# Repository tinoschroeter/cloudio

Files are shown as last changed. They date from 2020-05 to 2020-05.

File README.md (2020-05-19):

## Cloudio dein IoT Office buddy





Cloudio ueberwacht die Temperatur und Luftqualitaet. 
laesst sich mit Prometheus ansprechen um Grafana Metriken zu bekommen.

Und wenn es ganz schlimm wird, geht eine Slack Benachrichtigung raus.

[work in progress]

https://github.com/ozhantr/DigitLedDisplay

* Firebase 
  * Functions
  * Realtime Database 
  * Hosting
  * Authentication
* Prometheus
* Grafana
* Arduino
* ESP8266
* NodeJs
* JavaScript
* p5.js

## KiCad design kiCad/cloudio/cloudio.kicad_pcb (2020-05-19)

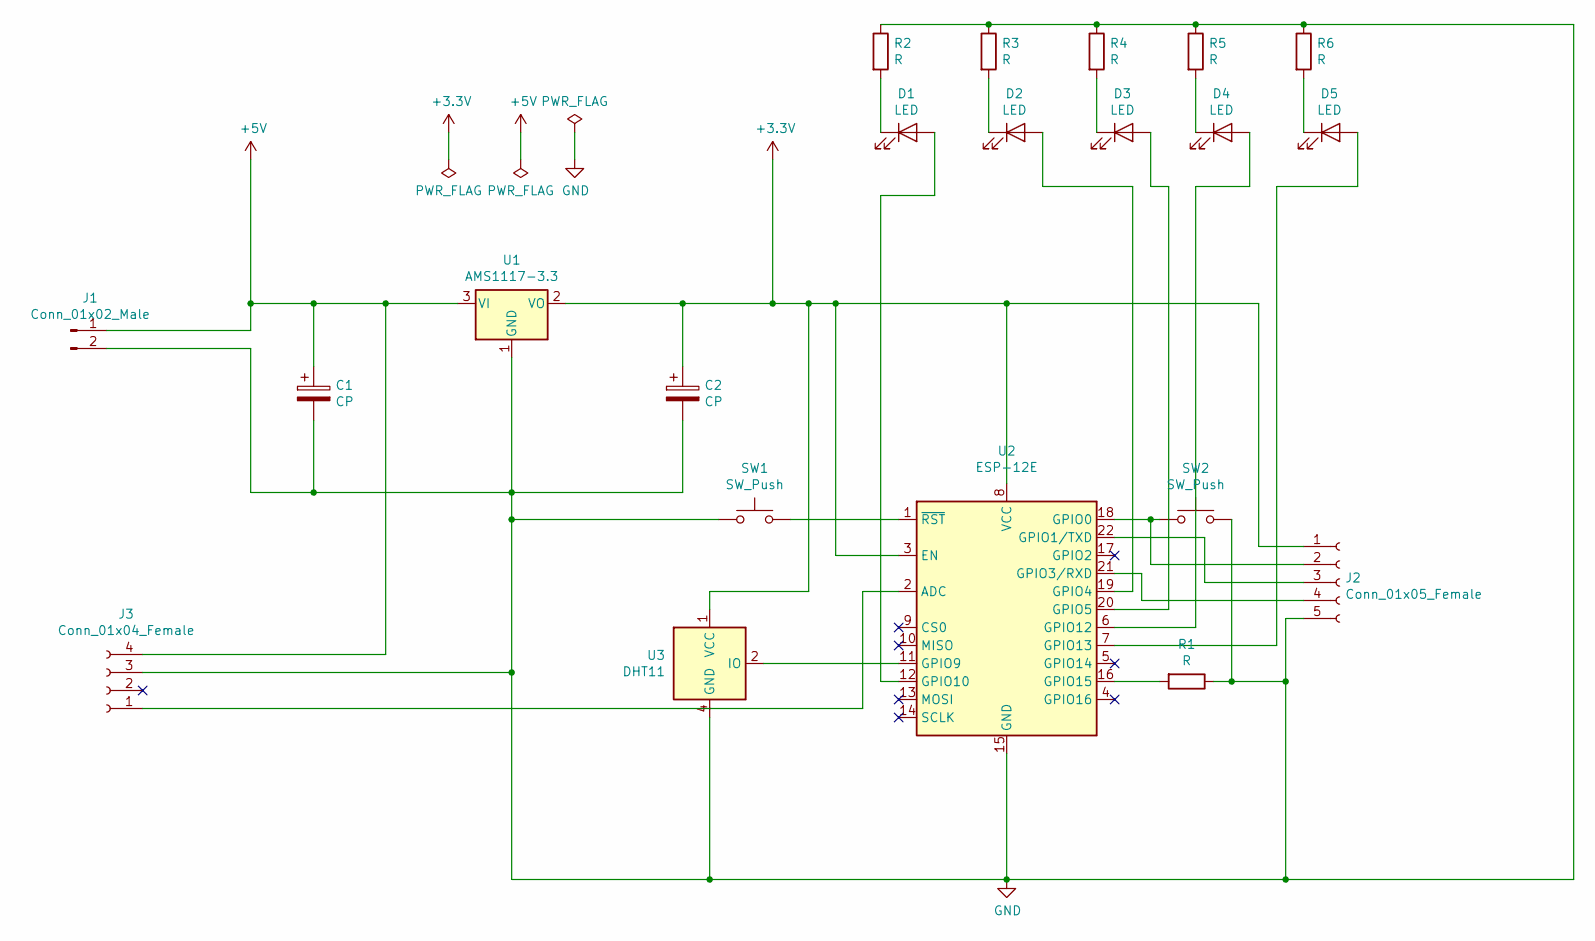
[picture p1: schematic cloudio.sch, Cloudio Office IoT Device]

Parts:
C1, C2: CP; CP_Radial_D4.0mm_P2.00mm
D1, D2, D3, D4, D5: LED; LED_Rectangular_W5.0mm_H2.0mm
J1: Conn_01x02_Male; PinHeader_1x02_P1.27mm_Vertical
J2: Conn_01x05_Female; PinHeader_1x05_P1.27mm_Vertical
J3: Conn_01x04_Female; PinHeader_1x04_P1.27mm_Vertical
R1, R2, R3, R4, R5, R6: R; R_0805_2012Metric_Pad1.15x1.40mm_HandSolder
SW1, SW2: SW_Push; SW_Push_1P1T_NO_CK_KSC7xxJ
U1: AMS1117-3.3; SOT-223-3_TabPin2
U2: ESP-12E
U3: DHT11; Aosong_DHT11_5.5x12.0_P2.54mm

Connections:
+3V3: C2.1, J2.1, U1.2 (VO), U2.3 (EN), U2.8 (VCC), U3.1 (VCC)
+5V: C1.1, J1.1, J3.4, U1.3 (VI)
GND: C1.2, C2.2, J1.2, J2.5, J3.3, R1.1, R2.1, R3.1, R4.1, R5.1, R6.1, SW1.1, SW2.2, U1.1 (GND), U2.15 (GND), U3.4 (GND)
unnamed: D1.1 (K), R2.2
unnamed: D1.2 (A), U2.12 (GPIO10)
unnamed: D2.1 (K), R3.2
unnamed: D2.2 (A), U2.19 (GPIO4)
unnamed: D3.1 (K), R4.2
unnamed: D3.2 (A), U2.20 (GPIO5)
unnamed: D4.1 (K), R5.2
unnamed: D4.2 (A), U2.6 (GPIO12)
unnamed: D5.1 (K), R6.2
unnamed: D5.2 (A), U2.7 (GPIO13)
unnamed: J2.2, SW2.1, U2.18 (GPIO0)
unnamed: J2.3, U2.22 (GPIO1/TXD)
unnamed: J2.4, U2.21 (GPIO3/RXD)
unnamed: J3.1, U2.2 (ADC)
unnamed: R1.2, U2.16 (GPIO15)
unnamed: SW1.2, U2.1 (~RST)
unnamed: U2.11 (GPIO9), U3.2 (IO)

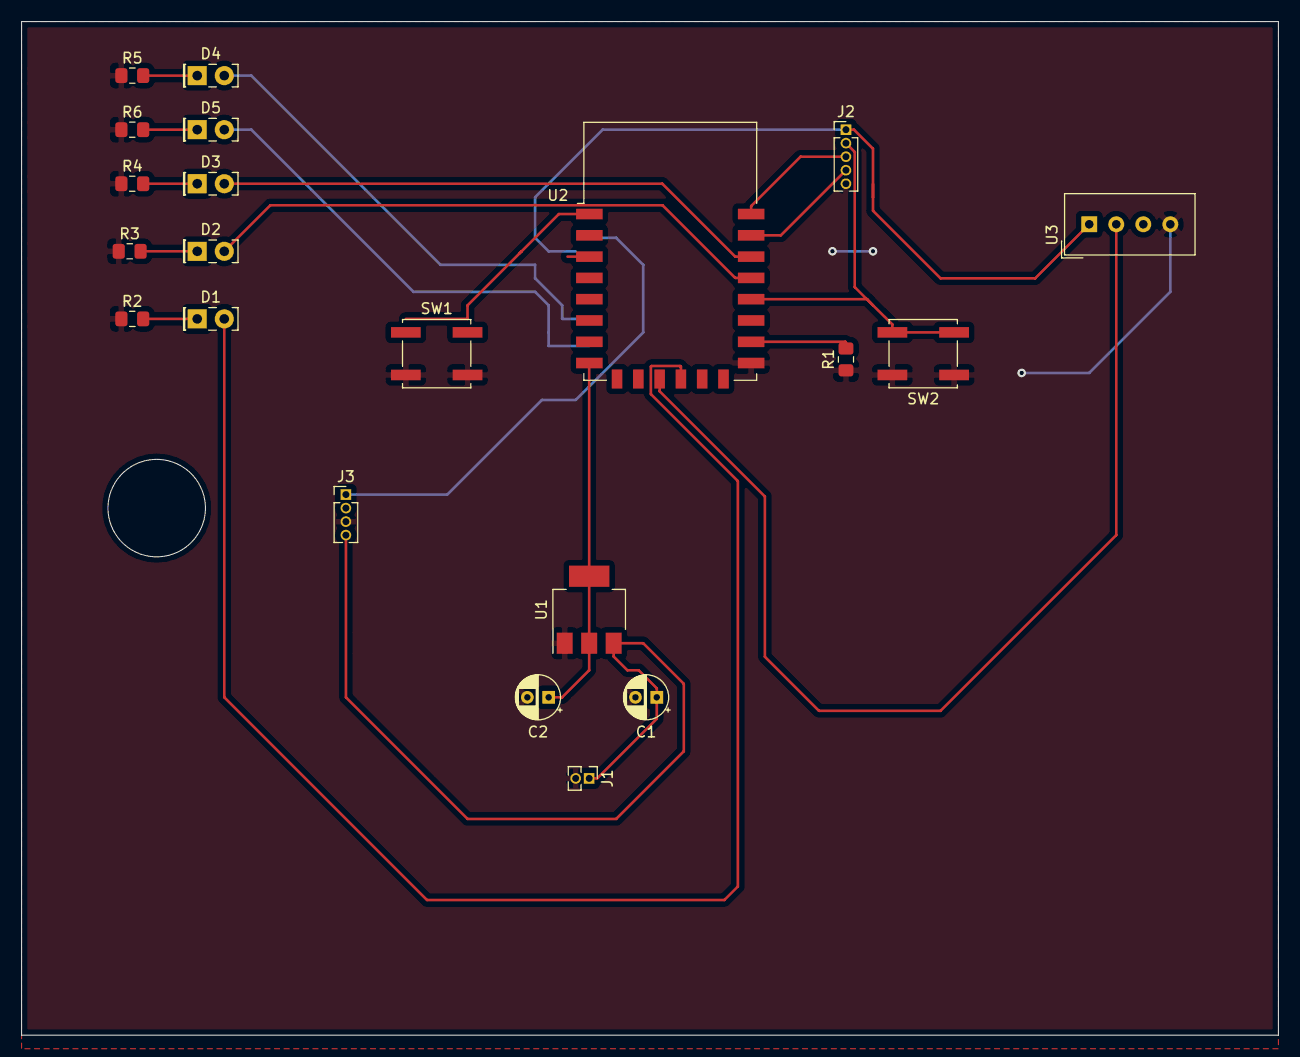
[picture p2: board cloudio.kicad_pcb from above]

Board: 2 copper layers, 118.1 x 95.2 mm, 21 parts (0 on the bottom side), 20 nets.

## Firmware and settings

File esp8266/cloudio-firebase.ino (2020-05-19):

// esp8266 community version: 2.5.2
#include <ESP8266WiFi.h>
#include <SoftwareSerial.h>
#include <FirebaseArduino.h>
#include <ArduinoJson.h>
#include <ESP8266HTTPClient.h>
#include <NTPClient.h>
#include <WiFiUdp.h>
#include <AsyncDelay.h>
#include "DHTesp.h"


#define FIREBASE_HOST "tino-test-41bd3.firebaseio.com"
#define FIREBASE_AUTH "++++++++++++++++++++++++"
#define WIFI_SSID "++++++++"
#define WIFI_PASSWORD "++++++++"

AsyncDelay delay_sensors;
AsyncDelay delay_led;

DHTesp dht;

String stringHumidity, stingTemperature;

const int numReadings = 30;
int readings[numReadings];
int readIndex = 0;   
int total = 0;    
int average = 0;
bool startReading = false;

int sensor = A0; // Analog Port
int air, airMap, gasStart, gasEnd;
int startDelay = 0;
String stringAir;
String ntp;

//const int WlanLED = 4;
//const int DataLED = 6;

const int ledPin = LED_BUILTIN;
int ledStatus;

// ntp offset fuer Berlin +1H
const long utcOffsetInSeconds = 3600;

WiFiUDP ntpUDP;
NTPClient timeClient(ntpUDP, 'de.pool.ntp.org', utcOffsetInSeconds);

void setup()
{
    // Start counting
    delay_sensors.start(1000, AsyncDelay::MILLIS);
    delay_led.start(500, AsyncDelay::MILLIS);

    // Debug console
    Serial.begin(115200);
    // connect to wifi.
    pinMode(ledPin, OUTPUT);
    WiFi.begin(WIFI_SSID, WIFI_PASSWORD);
    Serial.print("connecting");
    while (WiFi.status() != WL_CONNECTED)
    {
        Serial.print(".");
        delay(500);
    }
    Serial.println();
    Serial.print("connected: ");
    Serial.println(WiFi.localIP());

    Firebase.begin(FIREBASE_HOST, FIREBASE_AUTH);
    timeClient.begin();

    // setzt die "Datenbank" initial
    /*
       Firebase.setString("Data/tmp", "0"); // Temperatur
       Firebase.setString("Data/gas", "0"); // Luft Qualitaet
       Firebase.setString("Data/gas_sensor", "0"); // Luft Qualitaet
       Firebase.setString("Data/hum", "0"); // Luftfeuchtigkeit

       Firebase.setString("Data/time", "0"); // ZeitStempel
       Firebase.setString("Data/led", "0"); // LED

       Firebase.setString("Data/slack_hook", "not set"); // slack url
       Firebase.setString("Data/slack_hook", "false"); // slack alarm

       Firebase.setString("Data/gas_start", "49"); // bester Wert
       Firebase.setString("Data/gas_end", "90"); // schrlechtester Wert
       Firebase.setString("Data/gas_alarm", "20"); // wenn schlechter als der Wert gibt es ein Alarm/Slack Nachricht

       Firebase.setString("Data/tmp_alarm_up", "26"); // Alarm wenn Temperatur zu hoch
       Firebase.setString("Data/tmp_alarm_down", "17"); // Alarm wenn Temperatur zu niedrig

       Firebase.setString("Data/hum_alarm_up", "70"); // Alarm wenn Luftfeuchte zu hoch
       Firebase.setString("Data/hum_alarm_down", "10"); // Alarm wenn Luftfeuchte zu niedrig
     */

    dht.setup(5, DHTesp::DHT11); // GPIO 5 ist D1
    pinMode(sensor , INPUT); // GPIO 16 ist D0

      // initialize all the readings to 0:
      for (int thisReading = 0; thisReading < numReadings; thisReading++) {
        readings[thisReading] = 0;
     }
}

void loop()
{
    if (delay_sensors.isExpired()) {
        timeClient.update();
        Firebase.setString("Data/time", String(timeClient.getFormattedTime()));
        total = total - readings[readIndex];
        readings[readIndex] = analogRead(sensor);
        total = total + readings[readIndex];
        readIndex = readIndex + 1;
          if (readIndex >= numReadings) {
          readIndex = 0;
          startReading = true;
        }
         // Durchschnitt Luftqualitaetssensor
         if(startReading) {
           air = total / numReadings;
         }
        // map die Messwerte auf eine art Prozent 100% ist top
        gasStart = Firebase.getInt("Data/gas_start");
        Serial.print("getStart: ");
        Serial.println(gasStart);

        gasEnd = Firebase.getInt("Data/gas_end");
        Serial.print("getEnd: ");
        Serial.println(gasEnd);

        airMap = map(air, gasEnd, gasStart, 0, 100);
        Serial.print("airMap: ");
        Serial.println(airMap);
        stringAir = String(airMap);
        if(air > 0 && airMap < 110 && startDelay > 0) {
            Firebase.setString("Data/gas", stringAir);
            stringAir = String(air);
            Firebase.setString("Data/gas_sensor", stringAir);
        }
        // Temperatur
        delay(dht.getMinimumSamplingPeriod());

        int humidity = dht.getHumidity();
        Serial.print("humidity: ");
        Serial.println(humidity);

        float temperature = dht.getTemperature();
        Serial.print("temperature: ");
        Serial.println(temperature);
        
        if(temperature > 0) {
            stringHumidity = String(humidity);
            stingTemperature = String(temperature);
            Firebase.setString("Data/hum", stringHumidity);
            Firebase.setString("Data/tmp", stingTemperature);
            delay_sensors.repeat();
        }
        startDelay++;
    }

    if (delay_led.isExpired()) {
        // LED Status
        ledStatus = !Firebase.getInt("Data/led");
        if (ledStatus >= 0) {
            digitalWrite(ledPin, ledStatus);
        }
        delay_led.repeat();
    }
}
